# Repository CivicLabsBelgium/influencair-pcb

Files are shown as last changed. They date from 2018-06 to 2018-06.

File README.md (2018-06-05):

# influencair-pcb

A most simple version we could came up with for the luftdaten sensor.


(!! be carefull PCB Qty is still 250 !!)

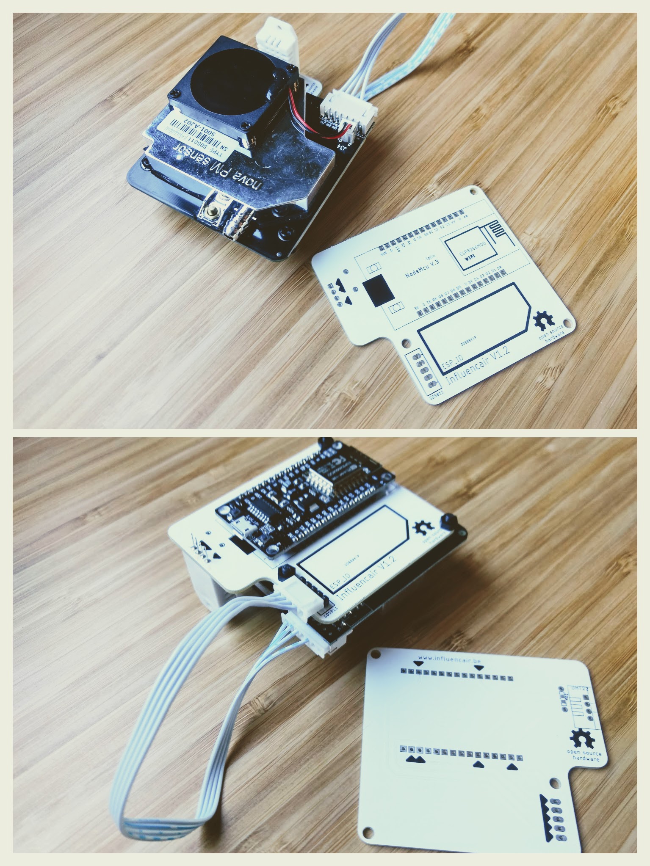
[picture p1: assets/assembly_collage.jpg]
assembled pcb


### BOM (bill of material)
- 1 x [NodeMcu V3 Lolin](https://www.aliexpress.com/item/LoLin-V3-NodeMcu-Lua-CH340G-ESP8266-WIFI-Internet-Development-Board-Module-Free-Shipping/32768126855.html)
- 1 x [DHT22](https://www.aliexpress.com/item/DHT22-AM2302-Digital-Temperature-and-Humidity-Sensor-Replace-SHT11-SHT15/32651317108.html)
- 1 x [SDS011 PM sensor + included white cable](https://www.aliexpress.com/item/Nova-PM-sensor-SDS011-High-precision-laser-pm2-5-air-quality-detection-sensor-module-Super-dust/32606349048.html) 
- 1 x [JST 5pin angled connector](https://www.aliexpress.com/item/100Pcs-2-54Mm-Spacing-series-Right-Angle-Bend-the-foot-Jst-Xh-Connector-Pin-Header-White/32819782475.html)
- 3 x [6mm nylon standoff](https://www.aliexpress.com/item/100Pcs-Spacer-Standoff-Black-PA66-M3-Female-x-M3-Female-Hex-Threaded-Nylon-Standoff-Threaded-Spacer/32800902427.html) 
- 6 x [5mm nylon screws](https://www.aliexpress.com/item/100Pcs-Lot-M3-Screws-Black-Nylon-Screws-5-10mm-Optional-Hex-Column-Standoff-Spacer-Phillips-Screw/32839259882.html)
- 1 x **optional** 10K Ohm resistor
- 2 x 90° angle pvc pipe 75mm
- 1 x flexible tube 8mm

### Info
- Designed with EagleCAD
- Based on [luftdaten](https://luftdaten.info) sensor
- Inspiration from https://github.com/Naesstrom/airrohr-PCB
- [Gerber files](https://github.com/CivicLabsBelgium/influencair-pcb/raw/master/influencair_2018-05-10.zip) made for seeedstudio fusion service. **Standard pcb settings** except color white, refects more heat then a black one.

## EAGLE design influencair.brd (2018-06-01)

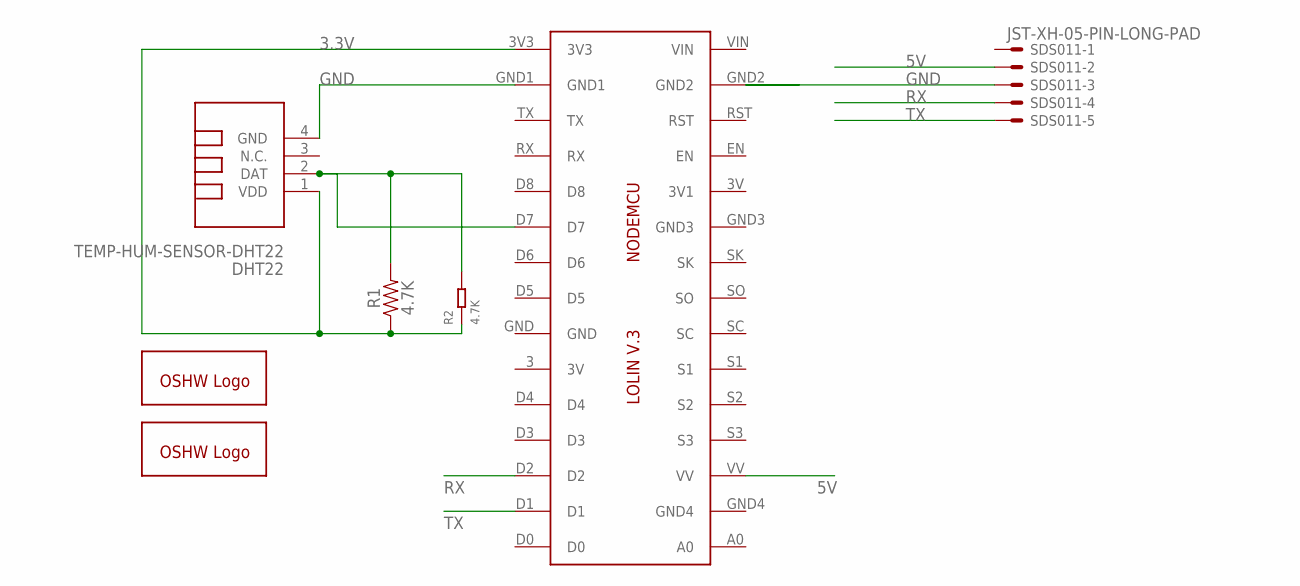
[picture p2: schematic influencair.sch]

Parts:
DHT22: TEMP-HUM-SENSOR-DHT22
GOLD_ORB_SM1, GOLD_ORB_SM2: OSHWLOGOLOGO8MM; OSHW_8MM
IC1: LOLINV3
R1: 4.7K; AXIAL-0.3
R2: 4.7K; R0805
SDS011: JST-XH-05-PIN-LONG-PAD; JST-XH-05-PACKAGE-LONG-PAD

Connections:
3.3V: DHT22.1 (VDD), IC1.3V3, R1.P$1 (1), R2.1
5V: IC1.VV, SDS011.2
GND: DHT22.4 (GND), IC1.GND1, SDS011.3
unnamed: DHT22.2 (DAT), IC1.D7, R1.P$2 (2), R2.2
RX: IC1.D2, SDS011.4
TX: IC1.D1, SDS011.5

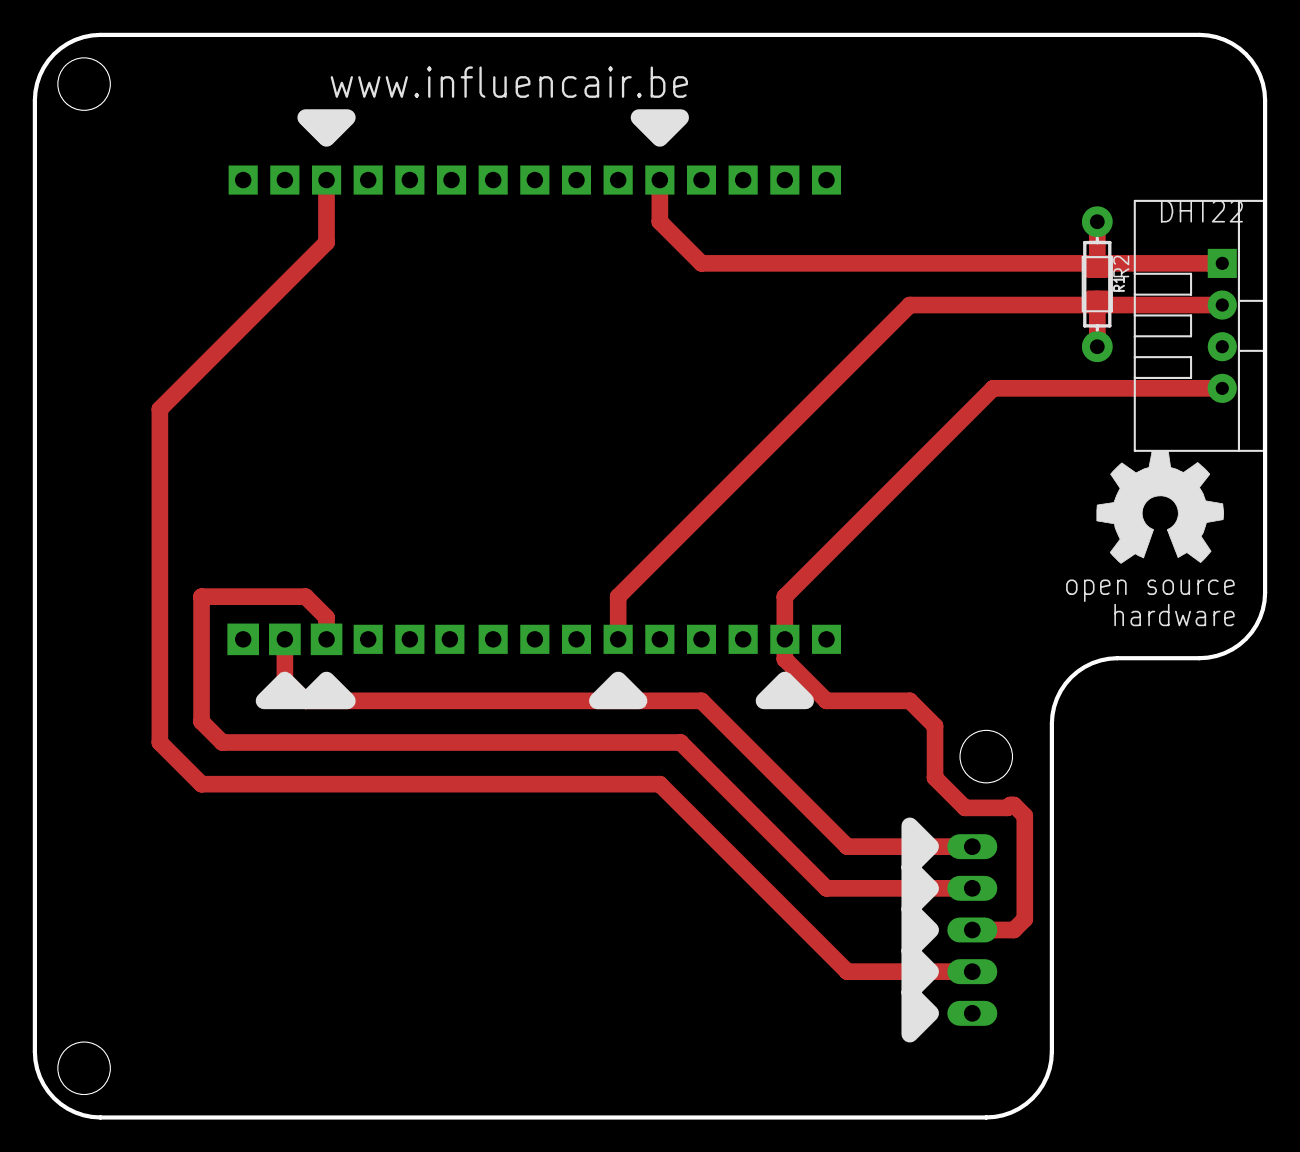
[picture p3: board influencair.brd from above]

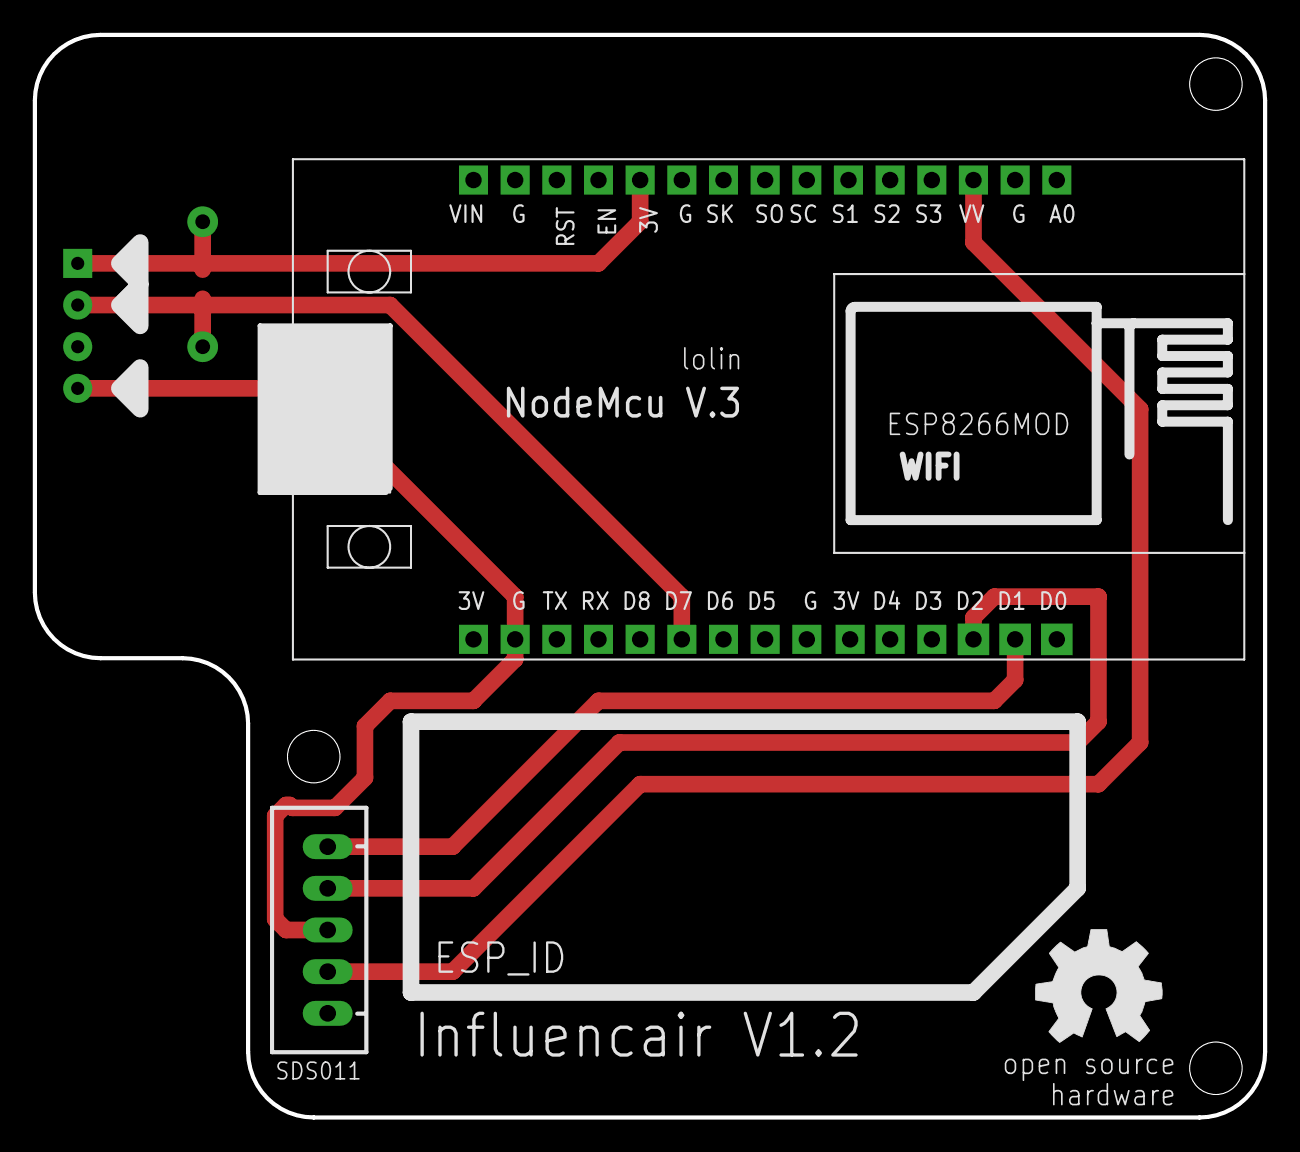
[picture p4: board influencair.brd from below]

Board: 2 copper layers, 75.0 x 66.0 mm, 7 parts (3 on the bottom side), 6 nets.

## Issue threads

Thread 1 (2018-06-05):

Add order details

lodagro, 2018-06-05:
Would it be possible to add order details for [https://www.seeedstudio.com](url) ?

Are the default settings ok? Or are other values needed?
Below is a screenshot for the default values.

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

Thanks.

Cinezaster, 2018-06-05:
@lodagro https://www.seeedstudio.com/Influencair-g-1130877
I did not change any setting except for the color and quantity.

lodagro, 2018-06-05:
@Cinezaster Thanks, i placed an order (using the above link, b.t.w for which the board dimensions are different compared to uploading the gerber zip archive)

Cinezaster, 2018-06-06:
@lodagro I know, for some reason it shows a different board dimension sometimes if you upload the zip file.

lodagro, 2018-06-23:
@Cinezaster Meanwhile the  boards i ordered arrived, i assembled two measurement stations. Very convenient.

:thumbsup:

Closed 2018-06-05.

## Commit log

2018-06-01 Source files
    [influencair.brd, influencair.sch]
2018-06-05 add pcb order via seeedstudio

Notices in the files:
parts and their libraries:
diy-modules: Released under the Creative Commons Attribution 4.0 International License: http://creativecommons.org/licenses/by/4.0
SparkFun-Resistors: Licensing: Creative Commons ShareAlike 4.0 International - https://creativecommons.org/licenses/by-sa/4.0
